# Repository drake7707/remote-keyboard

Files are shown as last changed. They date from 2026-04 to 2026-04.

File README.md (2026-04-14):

# Description

Remote Bluetooth (BLE) buttons targeting an **ESP32-C3 Zero** microcontroller acting as HID device and/or BTHome device

---

## Firmware

### Overview

Based on the original [BarButtons](https://jaxeadv.com/barbuttons) v1 firmware, this version replaces the STA-based OTA workflow with a **self-hosted WiFi Access Point** and a **browser-based configuration interface**.

### Features

| Feature | Description |
|---|---|
| **AP config mode** | Starts a WiFi AP (`RemoteButtons-Config` / `remotebuttons`) on demand |
| **Web keymap editor** | Configure Short Press and Long Press action (key + BLE target) for all 8 buttons across 3 keymap slots |
| **Per-key BLE target** | Each button press can target: *use target selector*, *broadcast to all HID peers*, *a specific bonded HID peer*, or *BT Home advertisement* |
| **Multiple keymaps** | Three independent keymap slots switchable on-device via Button 4 combos; active slot persisted across reboots |
| **NVS persistence** | All settings (keymaps, active slot, BLE name, battery/power flags) stored in ESP-IDF NVS flash; survive reboots and OTA updates |
| **OTA firmware update** | Upload a compiled `.bin` directly from the browser; device reboots automatically |
| **NimBLE BLE keyboard** | HID keyboard over BLE with secure bonding (Secure Connections, Just Works); CCCD state persisted per peer |
| **BTHome support** | Send button presses to your Home Assistant 
| **Multi-connection** | Up to 3 simultaneous BLE HID connections; cycle active target or broadcast to all with button combos |
| **LED status indicator** | Blink pattern varies by state — see table below |
| **Battery measurement** | Reads cell voltage via voltage divider (680 kΩ : 220 kΩ), reports percentage over BLE, and displays current voltage & percentage in the web config UI |
| **BLE power saving** | Optional negotiation of low-power connection parameters to reduce idle current draw |
| **Light sleep** | FreeRTOS tickless idle light sleep; drops CPU current from ~30 mA to a few µA when idle (BLE event window widened to 50–100 ms to allow idle time) |

### LED blink patterns

| State | ON duration | OFF duration |
|---|---|---|
| BT disconnected | 500 ms | 500 ms |
| Config mode | 100 ms | 3000 ms |
| BT connected | LED off (brief flash on keypress) | — |

### Entering / exiting config mode

1. **Hold Button 4 for ~5 seconds** — LED switches to rapid config-mode blink.
2. Connect to WiFi SSID **`RemoteButtons-Config`**, password **`remotebuttons`**.
3. Open **`http://192.168.4.1`** in a browser (works on mobile).
4. **Keymap Configuration** — set Short Press / Long Press action and BLE target per button for any of the three keymap slots, then click **Save & Reboot**.
5. **Firmware Update** — choose a `.bin` and click **Flash Firmware** for OTA update.
6. **BLE Bonds** — click **Clear BLE Bonds & Reboot** if the device no longer auto-connects.
7. **Device Settings** — change the BLE device name, enable/disable battery reading and BLE power saving, set max connections.
8. To exit config mode **without** saving any changes, tap Button 4 on the device.

> **Note:** Button 4 long-press is reserved as the config trigger and cannot be remapped.

> **Battery info:** when battery reading is enabled, the config page shows the current battery voltage (mV) and charge percentage measured at the moment config mode was entered.

### Web config UI

The config interface is a single-file HTML page served directly from flash. It is:

- **Mobile-first** — card-based layout, large tap targets, works comfortably on a phone or tablet.
- **Per-button cards** — each of the 8 buttons has its own expandable card showing Short Press and Long Press settings side-by-side on wider screens, stacked on mobile.
- **All settings in one page** — keymap editor, device settings (BLE name, battery, power saving, max connections), firmware OTA, bond management.

### Multiple keymaps

The firmware supports three independent keymap slots.  Each slot has its own Short Press and Long Press assignment for all 8 buttons.  All three slots are edited together in the web config UI and are saved to flash at the same time.

**Switching keymaps on-device (no config mode required):**

| Combo | Action |
|---|---|
| Hold Button 4, then press Button 1 | Switch to Keymap 1 |
| Hold Button 4, then press Button 2 | Switch to Keymap 2 |
| Hold Button 4, then press Button 3 | Switch to Keymap 3 |

After switching, the LED flashes **1, 2, or 3 times** to confirm which keymap is now active.  The selection is saved to flash immediately and survives reboots.

### Multi-connection

It's possible to connect multiple devices and send keystrokes to all of them (default) or to a specific target.

To save power BLE advertisements are only sent for 60 seconds after the first device is connected, if the second device has not connected in that time then it will never connect. When no devices are connected it will advertise indefintely and will restart advertisements when a device is connected, so turning the keyboard off and on while both devices are in range should connect.

Targets are automatically reconnected by the saved bonds, however only 1 direct advertisement is allowed at the same time and it defaults to undirected advertisements after a timeout, that means if device 2 is ready to connect but device 1 is not and the direct advertisements is directed towards device 1, device 2 will be able to see the undirected advertisements but will not automatically reconnect. This is a limitation of the BLE stack. So pair the device you use the most first, that way it connects to device 1 and will then attempt direct advertisements for device 2, which when in range will also automatically connect.

Targets are sorted on their MAC address so if 2 devices are connected, this first device in the cycle will always be the same regardless of order of connection.

** Switching target device **

| Combo | Action |
|---|---|
| Hold Button 4, then press Button 5 | Cycle between individual connected targets (LED blink count = slot index, long blink is broadcat to all) |

Each button mapping can also have its own fixed target (set in the web config UI), overriding the runtime target selector for that specific key.

### Application state diagram

```mermaid
stateDiagram-v2
    [*] --> BT_Disconnected : power on / boot

    BT_Disconnected : BT Disconnected<br>(LED slow blink 500/500 ms)
    BT_Connected    : BT Connected<br>(LED off, brief flash on keypress)
    Config_Mode     : Config Mode<br>(WiFi AP active, LED fast blink 100/3000 ms)

    BT_Disconnected --> BT_Connected    : host connects via BLE
    BT_Connected    --> BT_Disconnected : host disconnects

    BT_Disconnected --> Config_Mode     : Button 4 held ≥ 5 s
    BT_Connected    --> Config_Mode     : Button 4 held ≥ 5 s

    Config_Mode --> BT_Disconnected : tap Button 4 (exit without save)<br>or Save & Reboot web action<br>or Clear Bonds & Reboot web action<br>or Flash Firmware OTA web action
```

### Button keymap defaults

These factory defaults apply to **all three keymap slots** on a fresh device (i.e. when no saved keymap exists in flash).

| Button | Short press | Long press |
|---|---|---|
| 1 | `+` | repeat `+` |
| 2 | `-` | repeat `-` |
| 3 | `n` | `d` |
| 4 | `c`/exit config mode | enter config mode |
| 5 | Up Arrow | repeat Up Arrow |
| 6 | Left Arrow | repeat Left Arrow |
| 7 | Right Arrow | repeat Right Arrow |
| 8 | Down Arrow | repeat Down Arrow |

Long press set to **"Repeat short key"** (value `0`) means the short key auto-repeats while the button is held.
Any other key code sends that key exactly once on long press.

### Pin assignments (ESP32-C3 Zero)

| Signal | GPIO (legacy) | GPIO |
|---|---|---|
| LED | 6 | 2 |
| Row 0 | 2 | 8 |
| Row 1 | 1 | 7 |
| Row 2 | 0 | 6 |
| Col 0 | 3 | 3 |
| Col 1 | 4 | 4 |
| Col 2 | 5 | 5 | 
| Battery voltage divider | - | 0 |

Unfortunately ADC1 only works with GPIO0-5 so I had to remap the pins. The legacy version is for devices with the original pin layout, the default is with the new pin layout and this time I checked the pin functions thoroughly.



### Build & flash

1. Open the project in VSCode with the PlatformIO extension.
2. Set `const int DEBUG = 0;` in `src/main.h` before a production build.
3. Run **Build** (`pio run`) — the pre-build script automatically minifies `src/config.html` → `src/config.min.html`.
4. Run **Upload** to flash via USB.

---

## Hardware / Casing modifications of the original BarButtons design

The 3-D printed casing was modified from the original BarButtons design as follows:

- **M5 bolts** used instead of the original M4 bolts for the main assembly.
- **Heat-set inserts for M3 bolts** replacing the plain holes for the smaller fasteners.
- **Wemos D1 Mini pocket removed**; the cavity is resized to fit an **ESP32-C3 Zero** (smaller footprint).
- **LED hole changed to a 5 mm round hole, 5 mm deep**, so the dome of a standard 5 mm LED just barely protrudes at the surface. The original design used a much larger waterproof LED bezel; here the LED is simply pressed into the hole and sealed with RTV silicone.

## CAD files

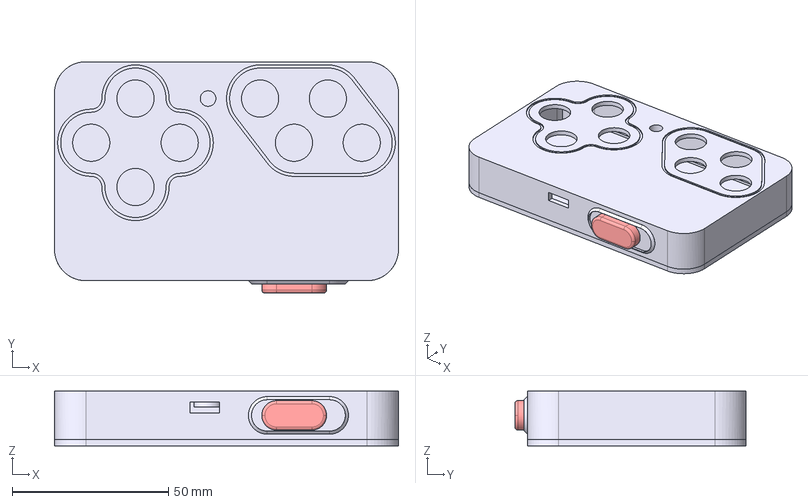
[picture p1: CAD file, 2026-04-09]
3D files/doublebassbuttons.step
110.0 x 74.0 x 17.5 mm
Top
Bottom
PowerSlider

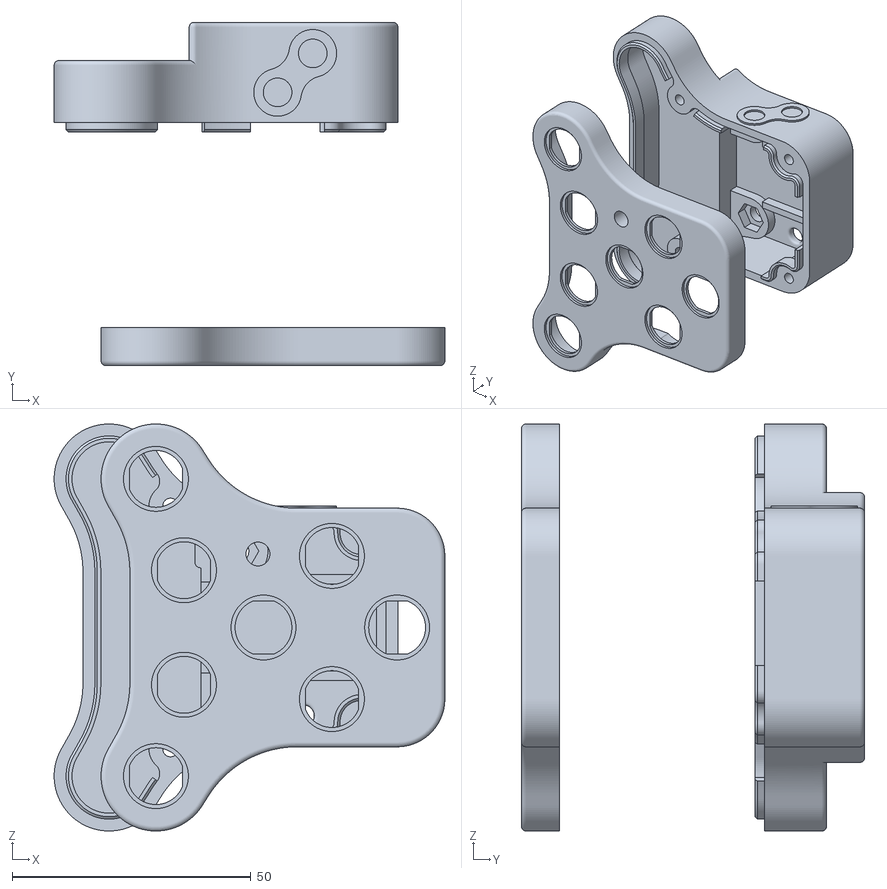
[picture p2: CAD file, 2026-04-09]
3D files/barbuttons_mod.stl
81.9 x 72.0 x 85.3

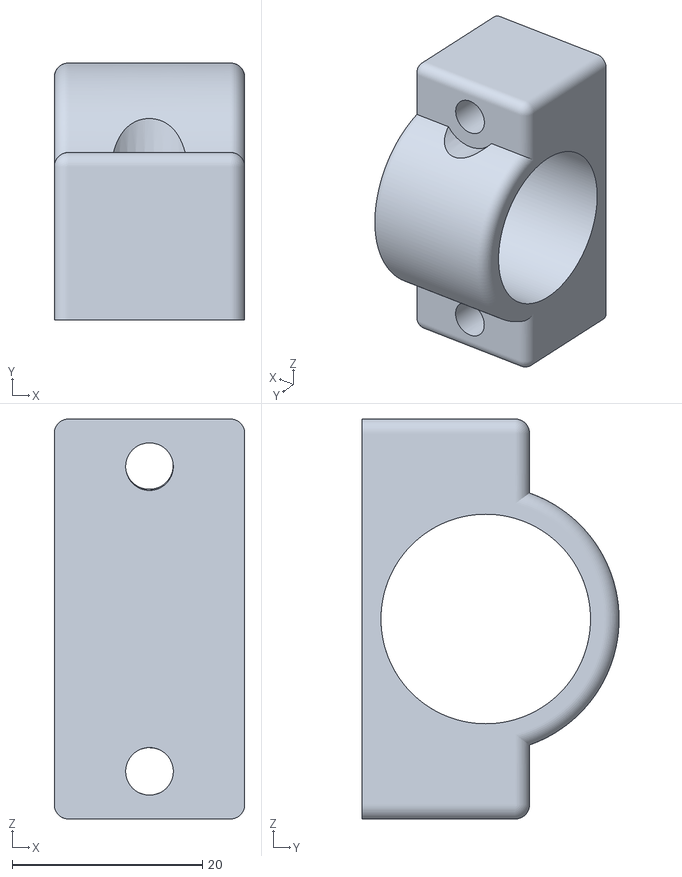
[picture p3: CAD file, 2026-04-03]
3D files/barbuttons_mod_clamp.stl
20.0 x 27.0 x 42.0

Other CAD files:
3D files/doublebassbuttons.FCStd

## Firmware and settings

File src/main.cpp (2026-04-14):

/*
   Remote Buttons firmware - Custom AP Keymap Configuration version

   Modified from original BarButtons v1 (https://jaxeadv.com/barbuttons).
   Instead of OTA firmware updates over STA, this version:
     - Hosts a WiFi Access Point ("RemoteButtons-Config")
     - Serves a web page at 192.168.4.1 for configuring the keymap of 8 buttons
     - Persists the keymap to NVS flash via the NVS API
     - Accepts OTA firmware (.bin) uploads directly from the browser

   HOW TO CONFIGURE / UPDATE:
     1. Hold Button 4 for ~5 seconds until the LED flashes rapidly.
     2. Connect to WiFi: SSID "RemoteButtons-Config", password "remotebuttons".
     3. Open http://192.168.4.1 in a browser.
     4. Keymap: set Short/Long Press actions per button, then "Save & Reboot".
     5. Firmware: choose a .bin file and press "Flash Firmware".
     6. To exit config mode without changes, tap Button 4 on the device.

   This work is licensed under the Creative Commons Attribution-NonCommercial 4.0
   International License. http://creativecommons.org/licenses/by-nc/4.0/
*/

#include <cstdio>
#include <nvs_flash.h>
#include <esp_netif.h>
#include <esp_event.h>
#include <esp_pm.h>
#include <freertos/FreeRTOS.h>
#include <freertos/task.h>

// ---------------------------------------------------------------------------
// Build flags
// ---------------------------------------------------------------------------
extern const int DEBUG = 1;       // Set to 1 only when Serial monitor is attached
extern const bool LEGACY = false; // Legacy has a different pin layout and no battery support

// ---------------------------------------------------------------------------
// Firmware version -- shown in the web config UI
// ---------------------------------------------------------------------------
const char FIRMWARE_VERSION[] = "1.5.0";

// ---------------------------------------------------------------------------
// Manager includes
// ---------------------------------------------------------------------------
#include "HardwareConfig.h"
#include "StatusLedManager.h"
#include "ble/BLEManager.h"
#include "config/ConfigManager.h"
#include "buttons/ButtonManager.h"
#include "BatteryManager.h"
#include "main.h"

// ---------------------------------------------------------------------------
// Global manager instances
// ---------------------------------------------------------------------------
StatusLedManager ledManager;
BLEManager bleManager("Drakarah", 100);
ConfigManager configManager;
ButtonManager buttonManager;
BatteryManager batteryManager;

std::string currentOutputTarget = "";

// Apply the currently active keymap to ButtonManager.
// Call once in setup() and again whenever the active keymap changes.
void applyKeymap()
{
  for (int i = 0; i < 8; i++)
  {
    char btn = '1' + i;
    if (i == 3)
    {
      // Button 4: config trigger -- non-repeating, 5-second total hold threshold
      buttonManager.setButtonRepeating(btn, false);
      buttonManager.setButtonLongPressTime(btn, ButtonManager::LONG_PRESS_CONFIG_TIME);
    }
    else
    {
      // BT Home targets don't use key-repeat (they fire a broadcast on every
      // press event; repeating doesn't make sense for those).
      bool hasBTHome = (configManager.getShortEntry(i).target == TARGET_BTHOME ||
                        configManager.getLongEntry(i).target == TARGET_BTHOME);
      // Repeat mode when no distinct long-press action is configured (key == 0)
      // and no BT Home target is involved.
      buttonManager.setButtonRepeating(btn, !hasBTHome && configManager.getLongEntry(i).key == 0);
    }
  }
}

// ---------------------------------------------------------------------------
// Config mode -- starts the AP, runs the client loop, then restores BLE
// ---------------------------------------------------------------------------
void start_config_mode()
{
  if (DEBUG)
    printf("[MAIN] Entering config AP mode\n");

  ledManager.flashConfigModeEntry();

  // Collect the bond list while NimBLE is still active so the web UI can
  // offer each known peer as an HID target option.
  const auto bondList = bleManager.getBondedAddresses();

  // On ESP32-C3 the radio is shared; stop BLE before starting WiFi AP
  bleManager.end();
  vTaskDelay(pdMS_TO_TICKS(100));

  // Start AP and register web routes (also flashes the LED 5 times)
  // NOTE: ledManager status is intentionally NOT yet APP_CONFIG here.
  // Setting it before the button is released would immediately trigger
  // the on_short_press config-exit check. See drainButton below.
  {
    const bool batAvail = (!LEGACY && configManager.isBatteryEnabled());
    const int batMv = batAvail ? batteryManager.getLastVoltageMv() : -1;
    const int batPct = batAvail ? batteryManager.getLastPercent() : -1;
    configManager.beginConfigAP(bondList, batMv, batPct);
  }

  // Drain the button-4 RELEASED event that triggered config mode.
  // While status != APP_CONFIG the on_short_press handler will NOT set the exit flag.
  buttonManager.drainButton(3000);
  if (DEBUG)
    printf("[MAIN] Button released, entering config loop\n");

  // Only NOW switch to config-mode status so the exit check becomes active
  ledManager.setStatus(APP_CONFIG);
  ledManager.resetLedState();

  // esp_http_server handles requests in its own task; this loop just drives
  // the LED blink and watches for a Button-4 tap to exit config mode.
  while (!configManager.isExitRequested())
  {
    configManager.handleClient(); // no-op with esp_http_server
    buttonManager.update();       // tap of '4' calls on_short_press -> sets exit flag
    ledManager.update();
    vTaskDelay(pdMS_TO_TICKS(5));
  }

  configManager.endConfigAP();

  // Restart BLE with the (possibly updated) device name
  bleManager.begin(configManager.getBleName(), configManager.allowBLEPowerSaving(), configManager.getMaxBLEConnections());
  ledManager.setStatus(APP_BT_DISCONNECTED);
  ledManager.resetLedState();

  if (DEBUG)
    printf("[MAIN] Config mode exited, BLE restarting\n");
}

std::string getCurrentOutputTarget()
{
  const std::vector<std::string> connections = bleManager.getConnections();
  const auto it = std::find(connections.begin(), connections.end(), currentOutputTarget);

  // If current target no longer exists → go back to broadcast
  if (it == connections.end())
  {
    currentOutputTarget = "";
    ledManager.flashTargetChanged(-1);
  }
  return currentOutputTarget;
}

void toggleOutputTarget()
{
  const std::vector<std::string> connections = bleManager.getConnections();
  if (connections.empty())
  {
    currentOutputTarget = "";
    ledManager.flashTargetChanged(-1);
    return;
  }
  else if (connections.size() == 1)
  {
    if (DEBUG)
      printf("[MAIN] Only one connection, staying on BROADCAST\n");
    currentOutputTarget = "";
    ledManager.flashTargetChanged(-1);
    return;
  }

  // If currently broadcasting → go to first device
  if (currentOutputTarget.empty())
  {
    currentOutputTarget = connections[0];
    ledManager.flashTargetChanged(0);
  }
  else
  {
    auto it = std::find(connections.begin(), connections.end(), currentOutputTarget);

    // If current target no longer exists → go back to broadcast
    if (it == connections.end())
    {
      currentOutputTarget = "";
      ledManager.flashTargetChanged(-1);
    }
    else
    {
      size_t index = std::distance(connections.begin(), it);
      index++;

      if (index >= connections.size())
      {
        // Wrap back to broadcast (empty string)
        currentOutputTarget = "";
        ledManager.flashTargetChanged(-1);
      }
      else
      {
        currentOutputTarget = connections[index];
        ledManager.flashTargetChanged(index);
      }
    }
  }
  if (DEBUG)
    printf("[MAIN] Output target set to: %s\n", currentOutputTarget == "" ? "BROADCAST" : currentOutputTarget.c_str());
}

// ---------------------------------------------------------------------------
// High-level button event callbacks -- registered with ButtonManager
// ---------------------------------------------------------------------------

// Short press: tap (non-repeating buttons), or repeated fire (repeating buttons)
void on_short_press(char btn)
{
  const AppStatus status = ledManager.getStatus();

  // In config mode a tap of button 4 exits AP mode without saving
  if (status == APP_CONFIG)
  {
    if (btn == '4')
      configManager.setExitRequested(true);
    return;
  }

  const int idx = Config::btnIndex(btn);
  if (idx < 0)
    return;

  const auto &entry = configManager.getShortEntry(idx);

  // BT Home broadcast target: send a BTHome advertisement and return.
  if (entry.target == TARGET_BTHOME)
  {
    if (DEBUG)
      printf("[MAIN] Short press: %c -> BTHome broadcast\n", btn);
    bleManager.getAdvertisingManager().broadcastBTHomeButtonPress(
        BLEAdvertisingManager::BTHOME_BUTTON_PRESS, idx + 1);
    ledManager.flashButtonPressed(idx);
    return;
  }

  if (entry.key == 0)
    return;

  // Determine HID target: fixed MAC (TARGET_HID) or runtime selector (TARGET_SELECT).
  std::string target;
  if (entry.target == TARGET_HID)
    target = entry.mac; // empty string = broadcast to all
  else
    target = getCurrentOutputTarget(); // TARGET_SELECT

  if (DEBUG)
    printf("[MAIN] Short press: %c -> key=0x%02X (%d) to target %s\n",
           btn, entry.key, entry.key, target.empty() ? "BROADCAST" : target.c_str());

  if (bleManager.isConnected())
  {
    if (target != "" && !bleManager.isConnected(target))
    {
      ledManager.flashButtonPressError(idx);
    }
    else
    {
      bleManager.write(target, entry.key);
      ledManager.flashButtonPressed(idx);
    }
  }
  else
  {
    ledManager.flashButtonPressError(idx);
  }
}

// Long press: button held beyond its long-press threshold
void on_long_press(char btn)
{
  // Button 4 long-press always enters config mode, regardless of keymap
  if (btn == '4')
  {
    start_config_mode();
    return;
  }

  const int idx = Config::btnIndex(btn);
  if (idx < 0)
    return;

  const auto &entry = configManager.getLongEntry(idx);

  // BT Home broadcast target: send a BTHome long-press advertisement and return.
  if (entry.target == TARGET_BTHOME)
  {
    if (DEBUG)
      printf("[MAIN] Long press: %c -> BTHome broadcast\n", btn);
    bleManager.getAdvertisingManager().broadcastBTHomeButtonPress(
        BLEAdvertisingManager::BTHOME_BUTTON_LONG_PRESS, idx + 1);
    ledManager.flashButtonPressed(idx);
    return;
  }

  // Determine HID target: fixed MAC (TARGET_HID) or runtime selector (TARGET_SELECT).
  std::string target;
  if (entry.target == TARGET_HID)
    target = entry.mac; // empty string = broadcast to all
  else
    target = getCurrentOutputTarget(); // TARGET_SELECT

  if (DEBUG)
    printf("[MAIN] Long press: %c -> key=0x%02X (%d) to target %s\n",
           btn, entry.key, entry.key, target.empty() ? "BROADCAST" : target.c_str());

  if (entry.key == 0)
  {
    ledManager.flashButtonPressError(idx);
    return;
  }

  if (bleManager.isConnected())
  {
    if (target != "" && !bleManager.isConnected(target))
    {
      ledManager.flashButtonPressError(idx);
    }
    else
    {
      bleManager.write(target, entry.key);
      ledManager.flashButtonPressed(idx);
    }
  }
  else
  {
    ledManager.flashButtonPressError(idx);
  }
}

// Combo: 'pressed' was pressed while 'held' was already active
void on_combo(char held, char pressed)
{
  if (DEBUG)
    printf("[MAIN] Key combo: hold %c + press %c\n", held, pressed);

  if (held == '4')
  {
    if (pressed >= '1' && pressed <= '3')
      toggleKeymap(pressed);
    else if (pressed == '5')
      toggleOutputTarget();
    else if (pressed == '6')
      bleManager.getAdvertisingManager().startCycle();
    return;
  }

  // Look up configured combos for the active keymap
  const int keymapIdx = configManager.getActiveKeymap() - 1;
  const int count = configManager.getComboCount(keymapIdx);
  for (int j = 0; j < count; j++)
  {
    const ComboEntry &combo = configManager.getComboEntry(keymapIdx, j);
    if (combo.held != held || combo.pressed != pressed)
      continue;

    // BT Home target
    if (combo.target == TARGET_BTHOME)
    {
      if (DEBUG)
        printf("[MAIN] Combo: hold %c + press %c -> BTHome\n", held, pressed);
      bleManager.getAdvertisingManager().broadcastBTHomeButtonPress(
          BLEAdvertisingManager::BTHOME_BUTTON_PRESS, Config::btnIndex(pressed) + 1);
      ledManager.flashButtonPressed(Config::btnIndex(pressed));
      return;
    }

    if (combo.key == 0)
    {
      ledManager.flashButtonPressError(Config::btnIndex(pressed));
      return;
    }

    std::string target;
    if (combo.target == TARGET_HID)
      target = combo.mac;
    else
      target = getCurrentOutputTarget();

    if (DEBUG)
      printf("[MAIN] Combo: hold %c + press %c -> key=0x%02X to %s\n",
             held, pressed, combo.key, target.empty() ? "BROADCAST" : target.c_str());

    if (bleManager.isConnected())
    {
      if (target != "" && !bleManager.isConnected(target))
      {
        ledManager.flashButtonPressError(Config::btnIndex(pressed));
      }
      else
      {
        bleManager.write(target, combo.key);
        ledManager.flashButtonPressed(Config::btnIndex(pressed));
      }
    }
    else
    {
      ledManager.flashButtonPressError(Config::btnIndex(pressed));
    }
    return;
  }
}

void toggleKeymap(char pressed)
{
  int newKeymap = -1;
  if (pressed == '1')
    newKeymap = 1;
  else if (pressed == '2')
    newKeymap = 2;
  else if (pressed == '3')
    newKeymap = 3;

  if (newKeymap > 0)
  {
    if (DEBUG)
      printf("[MAIN] Key combo: hold 4 + press %c -> keymap %d\n", pressed, newKeymap);
    configManager.setActiveKeymap(newKeymap);
    applyKeymap();
    ledManager.flashKeymapChanged(newKeymap);
  }
}

// Battery reading event — fired by BatteryManager only when the percentage changes.
void on_battery_updated(uint8_t percent)
{
  if (DEBUG)
    printf("[MAIN] Battery: %d%%\n", percent);
  bleManager.setBatteryLevel(percent);
}

// ---------------------------------------------------------------------------
// ESP-IDF entry point
// ---------------------------------------------------------------------------
extern "C" void app_main()
{
  if (DEBUG)
    vTaskDelay(pdMS_TO_TICKS(1000)); // time to open Serial monitor after reset

  // NVS must be initialised before any NVS or NimBLE calls.
  esp_err_t ret = nvs_flash_init();
  if (ret == ESP_ERR_NVS_NO_FREE_PAGES || ret == ESP_ERR_NVS_NEW_VERSION_FOUND)
  {
    nvs_flash_erase();
    nvs_flash_init();
  }

  // TCP/IP stack and default event loop are required for WiFi AP (config mode).
  esp_netif_init();
  esp_event_loop_create_default();

  configManager.begin(FIRMWARE_VERSION);
  configManager.loadConfig();

  bleManager.begin(configManager.getBleName(), configManager.allowBLEPowerSaving(), configManager.getMaxBLEConnections());

  ledManager.begin(getLEDPin(LEGACY));

  // If "Clear BLE Bonds" was requested from the web UI, delete stored bonds
  // now that NimBLE is initialised. The flag was written before the reboot.
  if (configManager.isClearBondsRequested())
  {
    BLEManager::clearAllBonds();
    configManager.clearClearBondsFlag();

    if (DEBUG)
      printf("[MAIN] BLE bonds cleared on request.\n");
  }

  buttonManager.setPinConfiguration(getKeypadRowPins(LEGACY),
                                    getKeypadColPins(LEGACY));
  buttonManager.begin();

  applyKeymap();
  // Flash N times to indicate which keymap is active on boot
  ledManager.flashKeymapChanged(configManager.getActiveKeymap());

  buttonManager.setShortPressHandler(on_short_press);
  buttonManager.setLongPressHandler(on_long_press);
  buttonManager.setComboHandler(on_combo);

  if (!LEGACY && configManager.isBatteryEnabled())
  {
    batteryManager.begin(ADC_BATTERY_CHANNEL);
    batteryManager.setBatteryReadingHandler(on_battery_updated);
  }

  if (!DEBUG)
  {
    // Enable automatic light sleep when the CPU is idle.
    // Requires CONFIG_PM_ENABLE=y and CONFIG_FREERTOS_USE_TICKLESS_IDLE=y
    // in sdkconfig.defaults (already set).
    const esp_pm_config_t pm_config = {
        .max_freq_mhz = 160, // reduce from 160 to save power; BLE and WiFi still work fine at 80 MHz
        .min_freq_mhz = 40,  // lowest valid ESP32-C3 frequency that keeps all peripherals stable
        .light_sleep_enable = true,
    };
    if (esp_pm_configure(&pm_config) != ESP_OK)
      printf("[MAIN] Warning: power management configuration failed\n");
  }
  else
  {
    printf("[MAIN] Light sleep not enabled in DEBUG mode. If you want to debug light sleep issues change this because serial is not reliable in light sleep.\n");
  }

  if (DEBUG)
    printf("[MAIN] Setup complete.\n");

  const bool batteryEnabled = !LEGACY && configManager.isBatteryEnabled();

  // Main loop
  while (true)
  {
    buttonManager.update();

    if (batteryEnabled)
      batteryManager.update();

    // Track BLE connection state changes
    const AppStatus status = ledManager.getStatus();
    if (status == APP_CONFIG)
    {
    }
    else
    {
      if (bleManager.isConnected())
      {
        if (bleManager.getAdvertisingManager().isAdvertising() && status != APP_BT_CONNECTED_ADVERTISING)
        {
          ledManager.setStatus(APP_BT_CONNECTED_ADVERTISING);
          ledManager.resetLedState();
        }
        else if (!bleManager.getAdvertisingManager().isAdvertising() && status != APP_CONNECTED)
        {
          ledManager.setStatus(APP_CONNECTED);
          ledManager.resetLedState();
        }
      }
      else
      {
        if (status != APP_BT_DISCONNECTED && status != APP_CONFIG)
        {
          ledManager.setStatus(APP_BT_DISCONNECTED);
          ledManager.resetLedState();
        }
      }
    }

    // Drive LED blink pattern and any pending flash animation
    ledManager.update();

    vTaskDelay(pdMS_TO_TICKS(10));
  }
}

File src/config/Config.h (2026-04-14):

#pragma once

#include <cstdint>
#include <cstring>
#include "buttons/KeyCodes.h"

#define BLE_NAME_MAX_LEN 32
extern const char DEFAULT_BLE_NAME[];

// ---------------------------------------------------------------------------
// Per-key target type
// ---------------------------------------------------------------------------
enum KeyTarget : uint8_t {
  TARGET_SELECT = 0, // use the runtime target selector
  TARGET_HID    = 1, // send to a specific HID peer (or broadcast)
  TARGET_BTHOME = 2  // broadcast a BTHome advertisement
};

// ---------------------------------------------------------------------------
// One button action (short or long press)
// ---------------------------------------------------------------------------
struct KeyEntry {
  uint8_t   key    = 0;
  KeyTarget target = TARGET_SELECT;
  char      mac[18] = {}; // HID peer MAC ("" = broadcast all)
};

// ---------------------------------------------------------------------------
// One button combo action (hold one button, press another)
// ---------------------------------------------------------------------------
struct ComboEntry {
  char      held    = 0;   // ASCII of held button ('1'..'8'), 0 = unused
  char      pressed = 0;   // ASCII of pressed button ('1'..'8'), 0 = unused
  uint8_t   key     = 0;
  KeyTarget target  = TARGET_SELECT;
  char      mac[18] = {}; // HID peer MAC ("" = broadcast all)
};

// ---------------------------------------------------------------------------
// Config -- the full runtime configuration state of the device
// ---------------------------------------------------------------------------
struct Config {
  // Factory defaults (definitions in Config.cpp)
  static const uint8_t DEFAULT_SHORT[8];
  static const uint8_t DEFAULT_LONG[8];

  static const int MAX_COMBOS = 16; // per keymap slot

  KeyEntry  shortEntries[3][8]           = {};
  KeyEntry  longEntries[3][8]            = {};
  ComboEntry comboEntries[3][MAX_COMBOS] = {};
  uint8_t   comboCounts[3]               = {};
  int       activeKeymap                 = 1;
  bool      batteryEnabled               = false;
  bool      blePowerSaving               = false;
  uint8_t   maxBLEConnections            = 1;
  char      bleName[BLE_NAME_MAX_LEN + 1] = {};

  // Map a button character ('1'..'8') to a 0-based index; returns -1 if invalid.
  static int btnIndex(char key);
};

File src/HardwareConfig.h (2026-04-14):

#pragma once

#include <esp_adc/adc_oneshot.h>  // adc_channel_t

// ---------------------------------------------------------------------------
// HardwareConfig — pin assignments for the RemoteButtons board
// Edit this file when porting to a different board or PCB revision.
// ---------------------------------------------------------------------------

// Status LED
const int LED_PIN_LEGACY = 6;
const int LED_PIN = 2;

// Keypad matrix — column drive lines.
static const uint8_t KEYPAD_COL_PINS_LEGACY[3] = {3, 4, 5};  // battery disabled
static const uint8_t KEYPAD_COL_PINS[3]  = {3, 4, 5};  // battery enabled

inline uint8_t getLEDPin(bool isLegacy) {
  return isLegacy ? LED_PIN_LEGACY : LED_PIN;
}

// Returns the correct column-pin array for the given battery mode.
inline const uint8_t* getKeypadColPins(bool isLegacy) {
  return isLegacy ? KEYPAD_COL_PINS_LEGACY : KEYPAD_COL_PINS;
}

// Keypad matrix — row drive lines. I moved the pins for the rows because ADC1 only works on GPIO0-5, and I wanted to use GPIO0 for battery voltage sensing. 
// The legacy pinout is preserved for older hardware builds that don't have battery support.
static const uint8_t KEYPAD_ROW_PINS_LEGACY[3] = {2, 1, 0};
static const uint8_t KEYPAD_ROW_PINS[3] = {8, 7, 6};  

// Returns the correct row-pin array for the given battery mode.
inline const uint8_t* getKeypadRowPins(bool isLegacy) {
  return isLegacy ? KEYPAD_ROW_PINS_LEGACY : KEYPAD_ROW_PINS;
}


// Battery voltage sense — GPIO0 = ADC1 channel 0 (only active when battery is enabled).
// Voltage is read through a 680 kΩ / 220 kΩ voltage divider so that the
// li-ion cell voltage (up to 4.2 V) is scaled down to the ADC input range.
const adc_channel_t ADC_BATTERY_CHANNEL = ADC_CHANNEL_0; // GPIO0 → ADC1 CH0 on ESP32-C3

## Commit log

2026-03-28 Fix LED hole description: round 5mm hole 5mm deep, RTV sealed
    Agent-Logs-Url: https://github.com/drake7707/barbuttons-mod/sessions/b620c8b3-cc83-4150-b37a-6eda01d96c33
2026-03-29 Rename 'key' to 'button' in ButtonManager to reduce confusion with BLE key codes
    Agent-Logs-Url: https://github.com/drake7707/barbuttons-mod/sessions/c0017da1-197b-4e0c-b0c8-1e75751b068e
2026-03-29 add logging of button manager
2026-03-29 Fix combo detection: remove timing guard that broke same-scan-cycle combos
    Agent-Logs-Url: https://github.com/drake7707/barbuttons-mod/sessions/cc9bd3d0-c6cf-41c1-9df5-2f9bbcdbf5bb
    [ButtonManager.h, barbuttons_keymap.ino]
2026-03-29 Add multiple keymaps support with combo-based switching (4+1/4+2/4+3)
    Agent-Logs-Url: https://github.com/drake7707/barbuttons-mod/sessions/6ebf3152-4d7a-40c5-bf92-37213e7c1b4f
2026-03-29 Fix press() shifted-key bug and add comprehensive BLE debug logging
    Agent-Logs-Url: https://github.com/drake7707/barbuttons-mod/sessions/e603854e-f431-4566-95fc-51b340568ffe
    [barbuttons_keymap.ino]
2026-03-29 docs: update README with multiple keymap support and state diagram; add field/function comments to ButtonManager and ConfigManager
    Agent-Logs-Url: https://github.com/drake7707/barbuttons-mod/sessions/7cf34e91-141c-457d-9247-0dbe4d4b01ac
2026-03-30 Always flash LED on short press, remove auto-repeat skip guard
    Agent-Logs-Url: https://github.com/drake7707/barbuttons-mod/sessions/a4960e29-c5b2-4e15-898b-16f6f1a6988a
    [barbuttons_keymap.ino]
2026-03-30 Flash active keymap LED indicator on boot
    Agent-Logs-Url: https://github.com/drake7707/barbuttons-mod/sessions/6cb7f651-fb0e-49ae-bba5-a99311b1661d
2026-04-02 Add GitHub Actions build workflow for ESP32-C3
    Agent-Logs-Url: https://github.com/drake7707/barbuttons-mod/sessions/24b0275c-c2ab-4c13-821c-3779ec7a9c82
2026-04-02 fix: pass sketch file path directly to arduino-cli compile
    Agent-Logs-Url: https://github.com/drake7707/barbuttons-mod/sessions/72a69787-3537-4cae-b8c7-9b123b4d9edb
2026-04-02 fix: create properly-named sketch directory for arduino-cli compile
    Agent-Logs-Url: https://github.com/drake7707/barbuttons-mod/sessions/3f583108-c33d-43ce-a5b5-2f8c2b04a278
2026-04-03 Clamp for M5 BHCS
    [barbuttons_mod_clamp.stl]
2026-04-06 migrate: move to PlatformIO from Arduino IDE
    Agent-Logs-Url: https://github.com/drake7707/barbuttons-mod/sessions/3ef0941d-7606-4f1a-940c-6badd4f06a91
2026-04-06 fix: use esp_pm_config_esp32c3_t for ESP32-C3 chip
    Agent-Logs-Url: https://github.com/drake7707/barbuttons-mod/sessions/d4606724-4497-47ce-abe1-e64ee0500318
    [main.cpp]
2026-04-06 Port firmware from Arduino to ESP-IDF: inline Keypad, IDF GPIO/NVS/WiFi/HTTP/OTA
    Agent-Logs-Url: https://github.com/drake7707/barbuttons-mod/sessions/aa1578f8-7506-4eee-96c4-66a09cbaa46c
    [partitions.csv]
2026-04-06 Fix NimBLEDevice.h not found: replace NimBLE-Arduino with esp-nimble-cpp IDF component
    Agent-Logs-Url: https://github.com/drake7707/barbuttons-mod/sessions/79dca31c-168e-45f3-ba3a-e456fe6a08c9
2026-04-06 Add BT modem sleep + PHY power-down sdkconfig options; fix min_freq_mhz
    Agent-Logs-Url: https://github.com/drake7707/barbuttons-mod/sessions/726e7d7a-89fe-4a1e-b2cc-2ffe374584c1
    [main.cpp]
2026-04-06 refactor: replace setRowPins with setPinConfiguration; add symmetric getKeypadColPins helper
    Agent-Logs-Url: https://github.com/drake7707/barbuttons-mod/sessions/92c3c18a-3595-47a6-90ac-80f8aab727aa
    [ButtonManager.h, HardwareConfig.h, main.cpp]
2026-04-08 feat: move HTML to src/config.html; embed via PlatformIO; hide battery section on LEGACY builds; build both firmware variants in CI
    Agent-Logs-Url: https://github.com/drake7707/barbuttons-mod/sessions/80f4843b-1139-4a86-91a7-9936539e1618
2026-04-08 working config load, update firmware version, minify doesn't work with unicode still
    [main.cpp]
2026-04-09 Extra config parameter: BLE Power saving that disables/enables renegotiating connection parameters. On older android devices this caused disconnects
2026-04-09 move 3d files to its own folder
    [barbuttons_mod.stl, barbuttons_mod_clamp.stl, doublebassbuttons.FCStd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]
2026-04-10 Fix: remove redundant BAT_PCT_NO_READING constant and _lastPct re-initialization in BatteryManager.cpp
    Agent-Logs-Url: https://github.com/drake7707/remote-keyboard/sessions/751a6030-7aa9-4c73-a2f7-f369427e00d6
    [BatteryManager.cpp]
2026-04-11 clean up the led manager, blinky state for connected but advertising
2026-04-11 feat: add broadcastBTHomeButtonPress for compliant BTHome v2 button events
    Add BLEAdvertisingManager::broadcastBTHomeButtonPress(eventType, button):
    - Emits a 200 ms BTHome v2 advertisement (UUID 0xFCD2, device-info 0x44)
    with 8 Button objects (object ID 0x3A), only the pressed button non-zero
    - Stops any ongoing HID advertising, broadcasts, then restores HID
    advertising and restarts the normal cycle via the existing callback path
    - HID advertising is now set via explicit setAdvertisementData() so it can
    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
2026-04-11 feat: add BTHome packet ID (object 0x00) to advertisement payload
    Adds a monotonically incrementing uint8 packet ID (wraps 0–255) as BTHome
    object 0x00 immediately after the device-info byte. Home Assistant uses this
    to distinguish distinct button events from duplicate re-transmissions of the
    same advertisement, which prevents dropped/ignored presses.
    Agent-Logs-Url: https://github.com/drake7707/remote-keyboard/sessions/645b2314-5149-4bb9-bbcc-efce08085d14
    [BLEAdvertisingManager.h]
2026-04-11 refactor: enum KeyTarget, KeyEntry struct, single SETTINGSJSON via cJSON, bond list in beginConfigAP
    - Replace static const uint8_t TARGET_* with enum KeyTarget : uint8_t (per review)
    - Introduce struct KeyEntry { key, target, mac } to replace 6 parallel arrays (per review)
    - Collapse 6 accessors to 2: getShortEntry/getLongEntry (per review)
    - Pass bond list directly to beginConfigAP, remove setBondList (per review)
    - Use cJSON to build a single SETTINGSJSON covering ALL settings (per review)
    - Removes all individual _strReplace calls; no more inline HTML placeholders
    - TARGET_* constants exposed via JSON so JS always matches firmware
    - config.html: var CFG = SETTINGSJSON; JS populates D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
    [main.cpp]
2026-04-11 fix: file input styling, battery voltage/percent in config UI, update README
    - config.html: style input[type=file] with display:block, margin-bottom,
    padding so it doesn't butt up against the Flash Firmware button;
    add green battery badge (voltage mV + charge %) to battery-section
    when a reading is available
    - BatteryManager: store _lastMv per ADC read; expose getLastPercent() /
    getLastVoltageMv() getters
    - ConfigManager: beginConfigAP() now accepts optional batVoltageMv /
    batPercent params; injects them into SETTINGSJSON as batVoltageMv /
    batPercent
    - main.cpp: pass battery snapshot to beginConfigAP() before entering
    config loop
    - README: refresh feature table, config-mode ste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
    [BatteryManager.cpp, main.cpp]
2026-04-12 refactor: split ConfigManager into PersistenceManager and WebUIConfigManager
    Agent-Logs-Url: https://github.com/drake7707/remote-buttons/sessions/9ee76296-9250-4316-814b-dd82d6dc7bd2
2026-04-14 plan: introduce Config struct, make PersistenceManager purely stateless with loadConfig/saveConfig
    Agent-Logs-Url: https://github.com/drake7707/remote-buttons/sessions/f2af4d4c-bd84-4dfc-ba65-8213beeb5d93
2026-04-14 refactor: Config struct owns types/state, PersistenceManager purely stateless NVS I/O
    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
2026-04-14 plan: review and fix naming + encapsulation across all source files
    Agent-Logs-Url: https://github.com/drake7707/remote-buttons/sessions/6193cad7-b069-4d05-b314-cc4fcba6003f
2026-04-14 refactor: naming review + const correctness across all source files
    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
    [BLEAdvertisingManager.h, BatteryManager.cpp, ButtonManager.h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]
2026-04-14 refactor: comprehensive const + naming pass (full second review)
    Agent-Logs-Url: https://github.com/drake7707/remote-buttons/sessions/1bb7303b-a168-482c-b7fb-d4d582ee532e
2026-04-14 add button combo configuration to web UI and firmware
    Agent-Logs-Url: https://github.com/drake7707/remote-buttons/sessions/37fcf5c1-d776-49dd-9c42-94228d8a210f
2026-04-14 fix alert messages for combo validation
    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
2026-04-14 fix combo UI: dedup check, filter pressed options, hide add form by default, reset clears combos
    Agent-Logs-Url: https://github.com/drake7707/remote-buttons/sessions/711c519c-3deb-4eb0-9064-acdc1968a93a
2026-04-14 refactor to make led status more clear instead of writing flashled everywhere
2026-04-14 flash errors when target is not connected
    [StatusLedManager.cpp, StatusLedManager.h, main.cpp]
